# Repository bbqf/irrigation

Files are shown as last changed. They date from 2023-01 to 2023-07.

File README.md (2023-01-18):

# Automated Irrigation system
Homebrew automated Irrigation system based on ESP32

Bill of materials:
* ESP32 based controllers (AZ-Delivery ESP32 DevKitC V2 ESP32-WROOM-32)
* Capacitive Soil Moisture Sensor v 1.2 (AZ-Delivery)
* KF-301 Relay Module with Low-level Trigger (AZ-Delivery)
To be continued...

```mermaid
C4Component
title Automated Irrigation system
Enterprise_Boundary(bc, "Logic") {
  System_Boundary(blc, "Logic Controller") {
    System(SN, "NodeRed")
    Rel(SQ1, SN, "Get Sensor Readings")
    Rel(SQ2, SN, "Receive Status Readings")
    Rel(SN, CQ1, "Send open/close commands")
  }
}

Enterprise_Boundary(bi, "Irrigation") {
  System_Boundary(bmq, "MQTT Broker") {
    SystemQueue(SQ2, "stat/moisture1")
    SystemQueue(SQ1, "stat/relay1")
    SystemQueue(CQ1, "cmnd/relay1")
  }
  System_Boundary(bs, "Soil Sensor Controller") {
    System(C1, "Soil Sensor Controller")
    System(S1, "Soil Moisture Sensor")
    BiRel(S1, C1, "")
  }
  System_Boundary(bv, "Valve Controller") {
    System(V1, "Water Valve")
    System(R1, "Relay1")
    System(C2, "Water Valve Controller")
    BiRel(V1, R1, "")
    BiRel(R1, C2, "")
  }
  
Rel(C1, SQ2, "Send readings periodically")
Rel(CQ1, C2, "Receive open/close commands")
Rel(C2, SQ1, "Send status periodically")
}
UpdateLayoutConfig($c4ShapeInRow="4", $c4BoundaryInRow="1")
```

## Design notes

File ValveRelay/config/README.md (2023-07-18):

# How to prepare and flash the configuration
## Preparation
1. Rename `sensor_config.csv.tmpl` to `sensor_config.csv`
1. Rename `sensor_data.csv` to `sensor_data.csv`
1. Check and change the `ssid`, `password`, `mqtt*` and `ntpServer` data values in the `sensor_data.csv`
1. Start the tool [mfg_gen.py](https://docs.espressif.com/projects/esp-idf/en/latest/esp32/api-reference/storage/mass_mfg.html) like
    
    mass_mfg.py generate sensor_config.csv sensor_data.csv VR 0x3000
1. Make sure the tool doesn't report any errors and `bin/VR.bin` file is successfully created
## Flashing
1. Flash the resulted `bin/VR-1.bin` file with the esptool.py at the address **0x9000**
    
    esptool.py -p COM9 write_flash 0x9000 bin\VR-1.bin

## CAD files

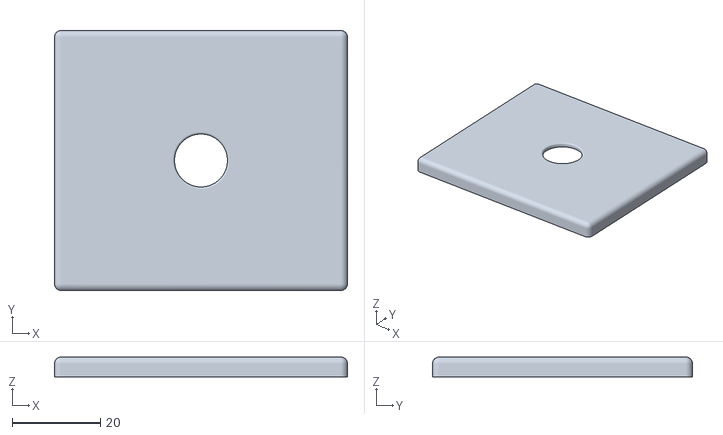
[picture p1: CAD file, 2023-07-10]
MoistureSensor/3d/MCU-Box-TopCut.stl
66.5 x 59.0 x 4.50

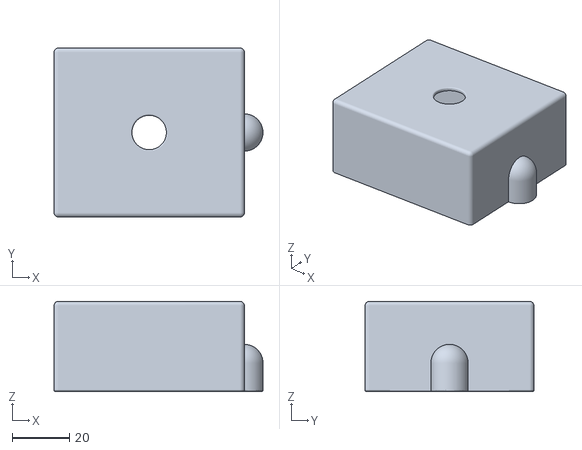
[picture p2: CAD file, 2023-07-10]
MoistureSensor/3d/MCU-Box-Top.stl
73.0 x 59.0 x 31.5

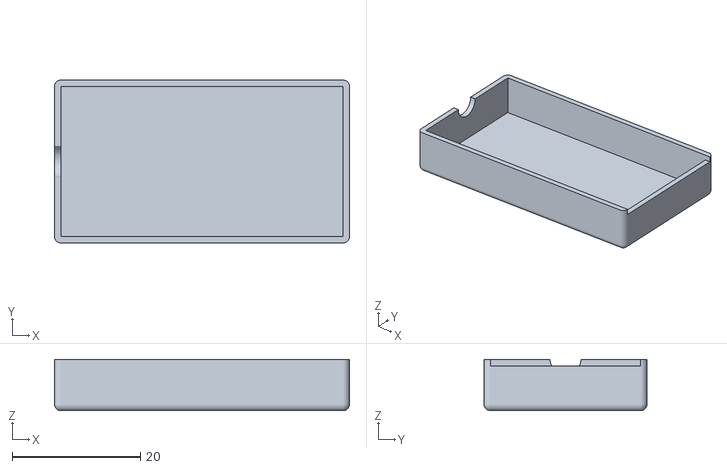
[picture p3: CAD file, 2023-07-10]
MoistureSensor/3d/MCU-Box-SensorBoxTop.stl
46.0 x 25.4 x 8.00

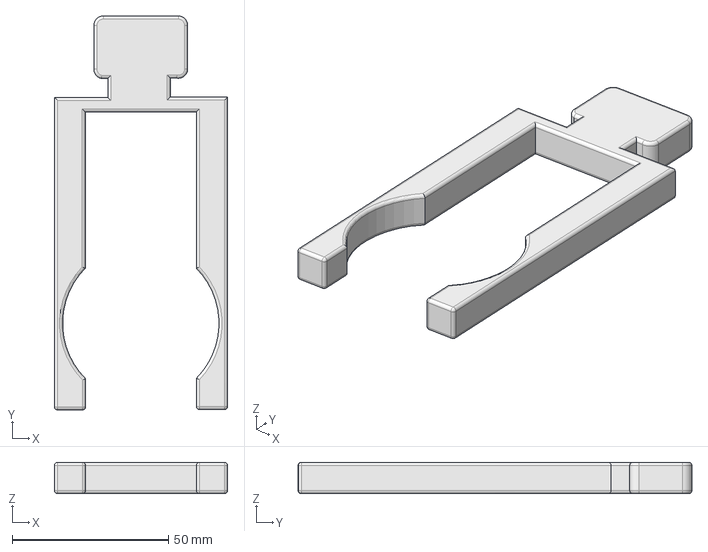
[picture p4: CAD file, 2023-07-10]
MoistureSensor/3d/Holder.FCStd
55.4 x 126.0 x 10.0 mm

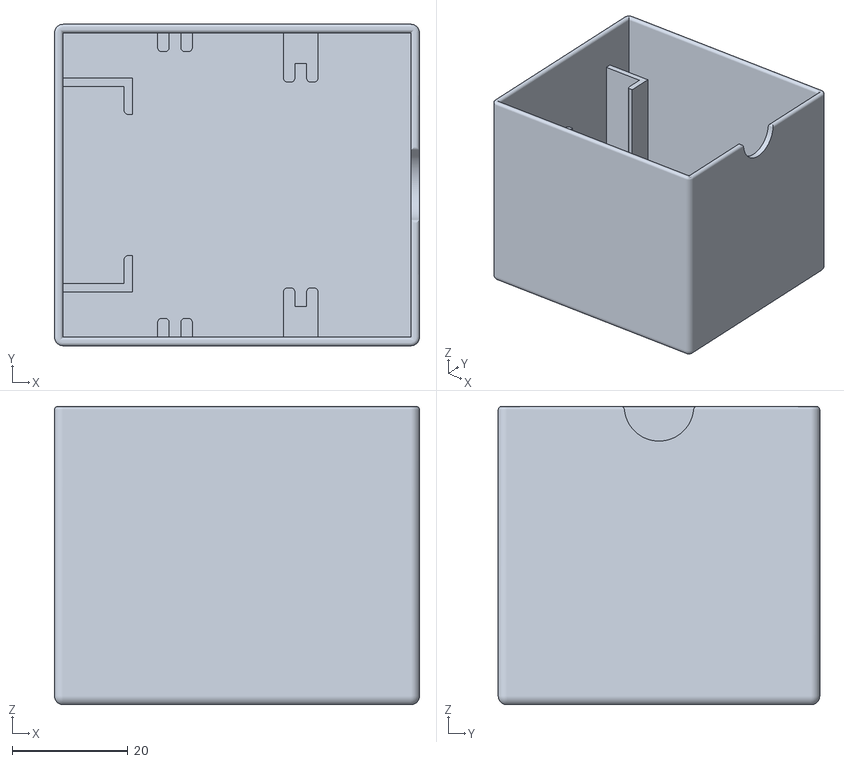
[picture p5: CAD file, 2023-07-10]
MoistureSensor/3d/MCU-Box-Bottom.stl
63.0 x 55.5 x 51.5

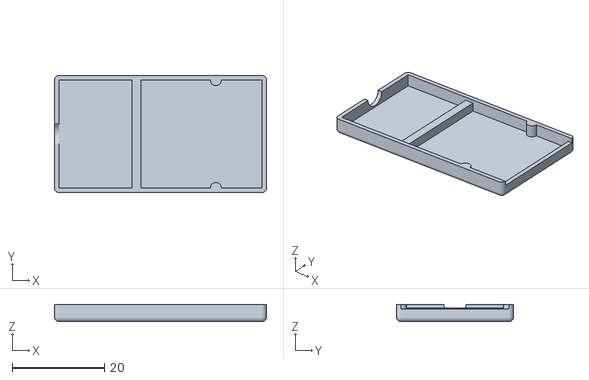
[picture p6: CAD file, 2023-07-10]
MoistureSensor/3d/MCU-Box-SensorBoxBottom.stl
46.0 x 25.4 x 3.75

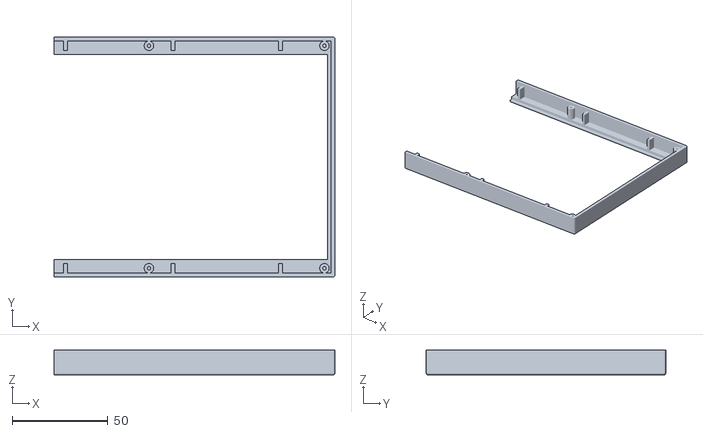
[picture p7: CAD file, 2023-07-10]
MoistureSensor/3d/Multisolarpanel-Screws-Top-Slice.0.stl
146.5 x 125.0 x 13.0

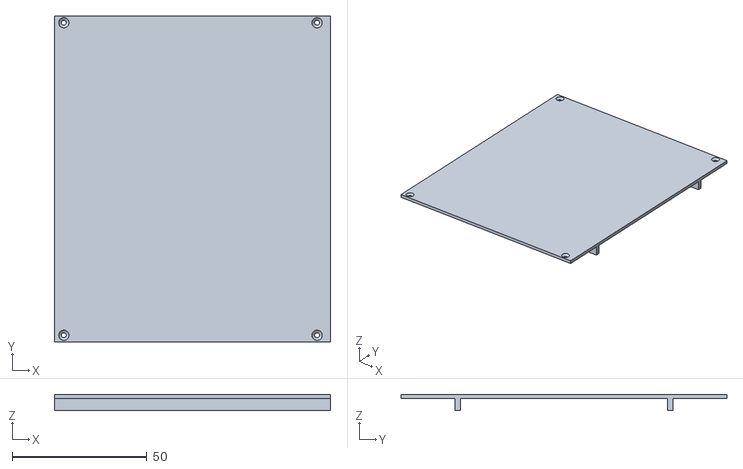
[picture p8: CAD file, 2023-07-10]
MoistureSensor/3d/Multisolarpanel-Screws-Back-Slice.1.stl
102.5 x 121.0 x 6.00

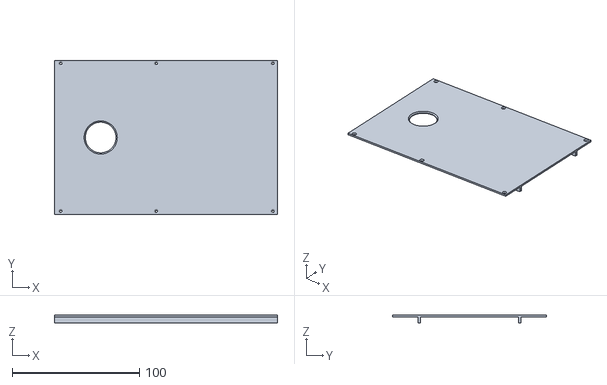
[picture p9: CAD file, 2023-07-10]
MoistureSensor/3d/Multisolarpanel-Screws-Back-Slice.0.stl
175.0 x 121.0 x 6.00

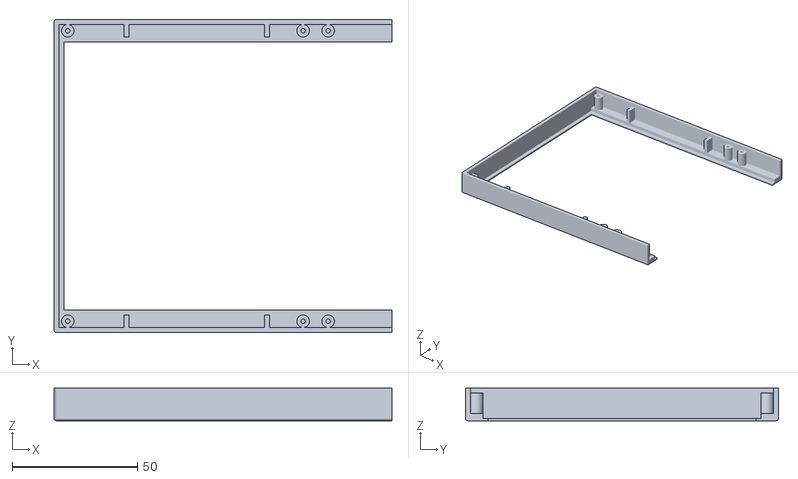
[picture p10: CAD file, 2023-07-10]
MoistureSensor/3d/Multisolarpanel-Screws-Top-Slice.1.stl
135.0 x 125.0 x 13.0

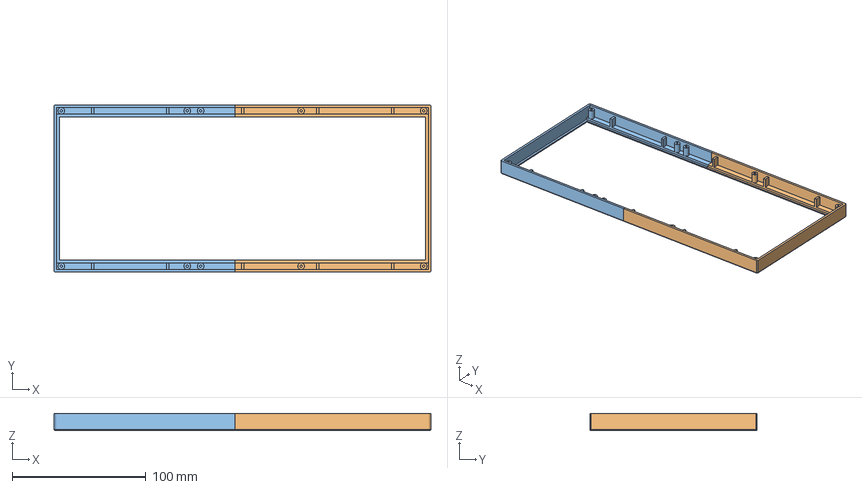
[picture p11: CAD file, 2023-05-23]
MoistureSensor/3d/Multisolarpanel-Screws.FCStd
281.5 x 125.0 x 13.0 mm
ClosedPanelTop
Slice001.0
Slice001.1

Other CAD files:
MoistureSensor/3d/Holder-Body.stl
MoistureSensor/3d/MCU-Box.FCStd

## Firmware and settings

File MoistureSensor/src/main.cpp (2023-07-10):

#include <Arduino.h>

#include <ArduinoJson.h>

#include "wifi_ops.h"
#include "mqtt.h"
#include "nvs_preferences.h"

#include "globals.h"

#define uS_TO_S_FACTOR 1000000 /* Conversion factor for micro seconds to seconds */

#define REV(x) #x

typedef  enum  {
  OP_EMPTY,
  OP_CHARGING,
  OP_DISCHARGING,
  OP_FULL
} OpStatus;

int initialBatteryReading = 0;

#include <stdio.h>

// Functions does cMeausrements measures on the specified pin and returns the average cutting off max and min values
uint16_t readAverage(int pin) {
    uint16_t arr[getCMeasures()] = {0};
    uint16_t i, sum = 0, max = 0, min = -1, count = 0;
    float avg;

    // Find maximum and minimum values in the array
    for (i = 0; i < getCMeasures(); i++) {
        arr[i] = analogRead(pin);
        if (arr[i] > max) {
            max = arr[i];
        }
        if (arr[i] < min) {
            min = arr[i];
        }
        delay(10);
    }

    log_i("Max: %d, Min: %d", max, min);
    // Calculate the sum of the array excluding the maximum and minimum values
    for (i = 0; i < getCMeasures(); i++) {
        if (arr[i] != max && arr[i] != min) {
            sum += arr[i];
            count++;
        }
    }
    log_i("Count: %d", count);
    if (count==0) {
      count=1;
      sum=arr[0];
    }
    // Calculate the average
    avg = (float) sum / count;

    return (uint16_t) avg;
}

float convertBatteryAbsToV(int batteryAbs) {
  return ((float)(batteryAbs - getBattCorrValue())*2/1000);
}

int convertBatteryRel(int val) {
  int battPct = map(val, getBattEmptyAbs(), getBattFullAbs(), 0, 100);
  if (battPct < 0) {
    battPct = 0;
  } else if (battPct > 100) {
    battPct = 100;
  }
  return(battPct);
}

int readBattAbs() {
  int battValue = 0;
 
  battValue = readAverage(getBatteryPin());  
  Serial.printf("BatteryAbs: %d\n",battValue);
  return battValue;
}

const OpStatus getOperationalStatus() {
  int batt = readBattAbs();
  OpStatus status = OP_DISCHARGING;
  if (batt <= getBattEmptyAbs()) {
    status = OP_EMPTY;
  } else if (batt >= getBattFullAbs()) {
    status = OP_FULL;
  } else if (batt >= getBattChargeAbs()) {
    status = OP_CHARGING;
  }

  return status;
}

const char * convertOpStatusToString(OpStatus status) {

  switch (status) {
    case OP_EMPTY: return("Empty"); break;
    case OP_CHARGING: return("Charging"); break;
    case OP_DISCHARGING: return("Discharging"); break;
    case OP_FULL: return("Full"); break;
  }

  return("Unknown");
}

time_t lastStatusSent;

int convertSensorRel(int val) {
  int mapped = map(val, getAirValue(), getWaterValue(), 0, 100);
  if (mapped < 0) {
    mapped = 0;
  } else if (mapped > 100) {
    mapped = 100;
  }
  return(mapped);
}

int readSensorAbs() {
  int soilMoistureValue = 0;
 
  soilMoistureValue = readAverage(getSensorPin());

  Serial.printf("MoistureAbs: %d\n", soilMoistureValue);
  return soilMoistureValue;
}

void sendStatus() {
  log_e("Enter");
  const size_t capacity = JSON_OBJECT_SIZE(10) + 128;
  
  DynamicJsonDocument doc(capacity);

  lastStatusSent = getEpochTime();
  //doc["time"] = lastStatusSent;
  doc["temperature"] = String(temperatureRead(), 1);
  int moisture = readSensorAbs();
  doc["moistureAbs"] = moisture;
  doc["moisture"] = convertSensorRel(moisture);
  int batt = readBattAbs();
#if ARDUHAL_LOG_LEVEL >= ARDUHAL_LOG_LEVEL_DEBUG
    doc["batteryAbs"] = batt;
    doc["initialBatteryAbs"] = initialBatteryReading;
#endif
  doc["batteryPct"] = convertBatteryRel(batt);
  doc["batteryV"] = String(convertBatteryAbsToV(batt), 2);

  doc["status"] = convertOpStatusToString(getOperationalStatus());
  doc["version"] = REV(REVISION);

  uint16_t ret = publish(doc.as<String>().c_str());
  log_d("publish(%s) returned: %d", doc.as<String>().c_str(), ret);
  if (ret == 0) {
    allowSleep();
  }
  log_e("Exit");
}

const char * isSleepAllowedStr() {
  return(isSleepAllowed() ? "true" : "false");
}

void setup()
{
  readPreferences();

  Serial.begin(115200);
  log_d("Enter");
  // put your setup code here, to run once:

  initialBatteryReading = readBattAbs();


#if ARDUHAL_LOG_LEVEL < ARDUHAL_LOG_LEVEL_DEBUG
  // In Debug mode we assume the battery is not connected (while USB is) and disable sleep on enpty battery
  if (getOperationalStatus() == OP_EMPTY) {
    log_e("Battery empty! Deep Sleep for %d seconds", getTimeToSleep());
    esp_sleep_enable_timer_wakeup(getTimeToSleep() * uS_TO_S_FACTOR);
    esp_deep_sleep_start();
  }
#endif

  log_d("Starting main setup");
  preventSleep();
  
  setupWiFi(setupMQTT);
  log_d("Setups done.");

  log_d("Exit");
}

void loop()
{
  log_d("Enter. sleepAllowed: %s", isSleepAllowedStr());
 
  if ((lastStatusSent == 0 || lastStatusSent + getUpdatePeriod() <= getEpochTime())) {
    sendStatus();
  }
  
  if (isSleepAllowed()) {
    log_i("Sleeping for %d seconds to complete async communication", getTimeToComm());
    delay(getTimeToComm() * 1000);
    
    log_i("Deep Sleep for %d seconds", getTimeToSleep());
    esp_sleep_enable_timer_wakeup(getTimeToSleep() * uS_TO_S_FACTOR);
    esp_deep_sleep_start();
    
  }

  delay(500); // We don't want to burn too many CPU cycles, so sleep for 1/2 sec if not allowed to deep sleep
  log_d("Exit");
}

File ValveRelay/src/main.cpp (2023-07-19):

#include <Arduino.h>

#include <ArduinoJson.h>

#include "wifi_ops.h"
#include "mqtt.h"
#include "nvs_preferences.h"

#include "globals.h"

#define uS_TO_S_FACTOR 1000000 /* Conversion factor for micro seconds to seconds */

#define REV(x) #x

#ifdef __cplusplus
extern "C"
{
#endif

  uint8_t temprature_sens_read();

#ifdef __cplusplus
}
#endif

bool isRelayOn;
time_t lastStatusSent;

void sendStatus() {
  log_e("Enter");
  const size_t capacity = JSON_OBJECT_SIZE(4) + 128;
  
  DynamicJsonDocument doc(capacity);

  lastStatusSent = getEpochTime();
  doc["time"] = lastStatusSent;
  doc["status"] = isRelayOn ? "ON" : "OFF";
  doc["temperature"] = (float)(temprature_sens_read() - 32) * 5 / 9;

  uint16_t ret = publish(doc.as<String>().c_str());
  log_d("publish() returned: %d", ret);
  if (ret == 0) {
    allowSleep();
  }
  log_e("Exit");
}

void relayOn()
{
  digitalWrite(getRelayPin(), HIGH);
  isRelayOn = true;
  Serial.println("RELAY is on");
  sendStatus();
}

void relayOff()
{
  digitalWrite(getRelayPin(), LOW );
  isRelayOn = false;
  Serial.println("RELAY is off");
  sendStatus();
}


const char * isSleepAllowedStr() {
  return(isSleepAllowed() ? "true" : "false");
}

void setup()
{
  readPreferences();

  Serial.begin(115200);
  log_e("Enter");
  pinMode(getRelayPin(), OUTPUT);
  log_d("Starting main setup");
  preventSleep();
  isRelayOn = false;
  relayOff();
  
  setupWiFi(setupMQTT);
  log_d("Setups done.");

  subscribeToCommand();
  log_d("Subscribed to command topic.");

  log_d("Exit");
}

void loop()
{
  log_d("Enter. isRelayOn=%s, sleepAllowed: %s", isRelayOn ? "true" : "false", isSleepAllowedStr());
  if ((lastStatusSent == 0 || lastStatusSent + getUpdatePeriod() <= getEpochTime())) {
    sendStatus();
  }

  if (!isRelayOn) { // Do not sleep at all if Relay is on
    while (!isSleepAllowed()) // If Relay is off, we wait until all communication/operations are completed. Warning: wait is endless!
    {
      delay(500);
    }

    log_i("Sleeping for %d seconds to complete async communication", getTimeToComm());
    delay(getTimeToComm() * 1000);
    if (!isRelayOn) { // Important: check if relay has just been turned on.
      log_i("Deep Sleep for %d seconds", getTimeToSleep() );
      esp_sleep_enable_timer_wakeup(getTimeToSleep()  * uS_TO_S_FACTOR);
      esp_deep_sleep_start();
    }
  }
  delay(500); // We don't want to burn too many CPU cycles, so sleep for 1/2 sec if relay is on.
  log_d("Exit");
}

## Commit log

2023-01-23 Initial Commit - Relay1/.gitignore
2023-02-05 Battery readings and Abs/Rel moisture
2023-02-08 Battery levels fixed
2023-02-08 Calibrating Battery values
2023-02-08 Calibrated sensor and increased update period to 30 min
2023-02-10 Fixing swapped sleep and update intervalls
    [main.cpp]
2023-02-14 Calibrating battery readings
2023-02-17 Averaging reads
    [MCU-Box-Compound.stl, MCU-Box-tryout.stl, MCU-Box.FCStd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]
2023-04-06 Swithing to Preferences
    [MCU-Box-Compound.stl, MCU-Box-tryout.stl, MCU-Box.FCStd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]
2023-04-07 Completed switch to the configuration
2023-04-18 Updated config and switched debugging permanently on
2023-05-23 Fixing broken links as well as adjusting frames
    [MCU-Box.FCStd, Multisolarpanel-Screws-1.FCStd, Multisolarpanel-Screws.FCStd]
2023-05-23 Fixed cable hole in the bottom part
    [MCU-Box.FCStd]
2023-07-10 updated 3d and moving time out of the mqtt messages
    [Holder-Body.stl, Holder.FCStd, MCU-Box-Bottom.stl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]
2023-07-19 Introducing flash_prefs for ValveRelay for now
